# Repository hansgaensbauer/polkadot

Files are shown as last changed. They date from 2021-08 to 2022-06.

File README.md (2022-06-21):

# polkadot
A low cost, standalone LoRa mesh network using STM32 and the SX1276.

## Firmware
The firmware implements a limited (and highly simplified) version of the AODV routing algorithm. Identical nodes running identical firmware can route a mesh automatically and efficiently without outside intervention. Additional nodes (which can also be running "factory" firmware) will route themselves when they power on. 

## Hardware





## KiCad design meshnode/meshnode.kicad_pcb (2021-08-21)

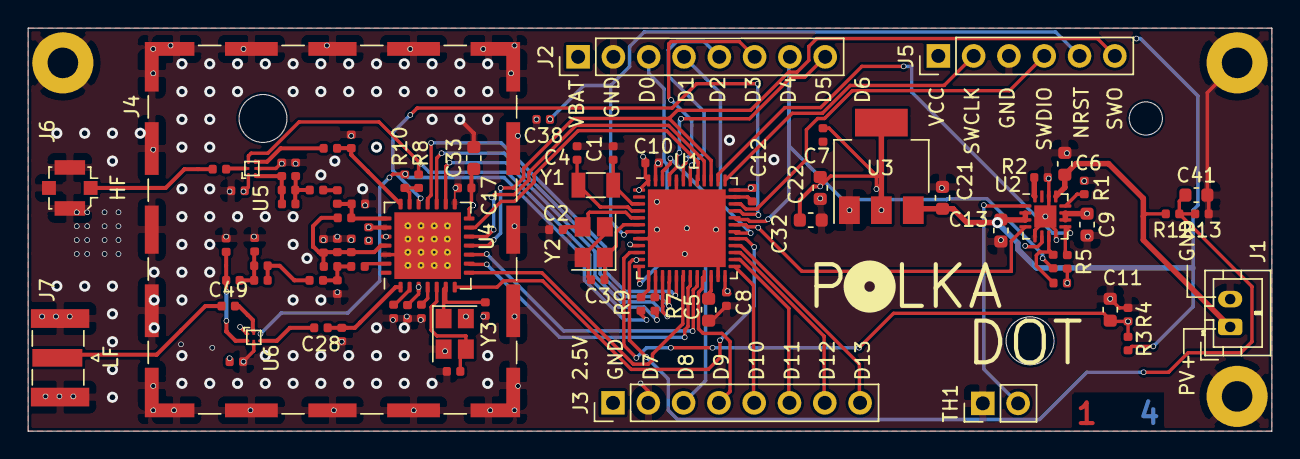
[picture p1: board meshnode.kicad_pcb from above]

Board: 4 copper layers, 89.5 x 29.0 mm, 88 parts (1 on the bottom side), 71 nets.

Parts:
BT1: Battery_Cell; BatteryHolder_Keystone_1042_1x18650
C1, C2, C3, C4, C15, C16, C24, C39: 15p; C_0402_1005Metric
C5, C9, C13: 4.7u; C_0603_1608Metric
C6, C21, C22: 1u; C_0603_1608Metric
C7, C8, C10, C12, C14, C17, C18, C19, C20, C38: 100n; C_0402_1005Metric
C11, C32, C33, C41: 10u; C_0603_1608Metric
C23: 1.5p; C_0402_1005Metric
C25: 10n; C_0402_1005Metric
C26: 33p; C_0402_1005Metric
C27: 18p; C_0402_1005Metric
C28, C35: 22p; C_0402_1005Metric
C29, C30, C47, C49: 47p; C_0402_1005Metric
C31: 3.3p; C_0402_1005Metric
C34: 4.7p; C_0402_1005Metric
C36: 2.7p; C_0402_1005Metric
C37: 1.2p; C_0402_1005Metric
C40: 1.8p; C_0402_1005Metric
C44: 6.8p; C_0402_1005Metric
C45, C46: 1n; C_0402_1005Metric
H1, H2, H3: MountingHole_Pad; MountingHole_2.2mm_M2_Pad
J1: Conn_01x02_Male; JST_PH_B2B-PH-K_1x02_P2.00mm_Vertical
J2, J3: Conn_01x08_Male; PinHeader_1x08_P2.54mm_Vertical
J4: RF_Shield_Two_Pieces; Laird_Technologies_BMI-S-203-F_26.21x26.21mm
J5: SWD; PinHeader_1x06_P2.54mm_Vertical
J6: Conn_Coaxial; U.FL_Molex_MCRF_73412-0110_Vertical
J7: Conn_Coaxial; SMA_Samtec_SMA-J-P-X-ST-EM1_EdgeMount
L1: 2.2n; L_0402_1005Metric
L2, L3: 33n; L_0402_1005Metric
L4: 18n; L_0402_1005Metric
L8: 10n; L_0402_1005Metric
L9: 12n; L_0402_1005Metric
L10: 6.2n; L_0402_1005Metric
L11: 15n; L_0402_1005Metric
R1: 1.18k; R_0402_1005Metric
R2: 1.13k; R_0402_1005Metric
R3, R4, R12: 1Meg; R_0402_1005Metric
R5, R6, R11: 1k; R_0402_1005Metric
R7, R8, R9, R10: 220; R_0402_1005Metric
R13: 100k; R_0402_1005Metric
TH1: 10k; PinHeader_1x02_P2.54mm_Vertical
U1: STM32F401CCUx; QFN-48-1EP_7x7mm_P0.5mm_EP5.6x5.6mm
U2: BQ24074RGT; VQFN-16-1EP_3x3mm_P0.5mm_EP1.6x1.6mm
U3: AZ1117-2.5; SOT-223-3_TabPin2
U4: SX1276; QFN-28-1EP_6x6mm_P0.65mm_EP4.8x4.8mm_ThermalVias
U5, U6: SKY13453-385LF; SKY13453
Y1: 32.786k; Crystal_SMD_3215-2Pin_3.2x1.5mm
Y2: 16Meg; Crystal_SMD_SeikoEpson_TSX3225-4Pin_3.2x2.5mm
Y3: 32Meg; Crystal_SMD_SeikoEpson_TSX3225-4Pin_3.2x2.5mm

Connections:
+2V5: C7.2, C8.2, C10.2, C12.2, C17.2, C19.2, C20.2, C22.1, C32.1, C33.1, C45.1, C46.1, J3.1, J5.1, R5.1, R6.1, U1.1, U1.9, U1.24, U1.36, U1.48, U3.2, U4.3, U4.14, U4.24, U5.1, U6.1
+4V: C9.1, U2.6, U2.10, U2.11
+BATT: BT1.1, C13.1, C21.1, J2.1, R3.2, U2.2, U2.3, U3.3
/CHG_~CE: U1.31, U2.4
/CS_X: U1.33, U4.19
/DIO0: U1.18, U4.8
/DIO1: U1.19, U4.9
/DIO2: U1.20, U4.10
/DIO4: U1.40, U4.12
/DIO5: U1.41, U4.13
/GPIO_0: J2.3, U1.12
/GPIO_1: J2.4, U1.30
/GPIO_2: J2.5, U1.42
/GPIO_3: J2.6, U1.43
/GPIO_5: J2.8, U1.45
/GPIO_6: J3.3, U1.46
/GPIO_7: J3.4, U1.21
/GPIO_8: J3.5, U1.25
/GPIO_9: J3.6, U1.26
/GPIO_10: J3.7, U1.27
/GPIO_11: J3.8, U1.28
/MISO: U1.16, U4.17
/MOSI: U1.17, U4.18
/NRST: C38.1, J5.5, U1.7
/RST: U1.29, U4.7
/RXTX: R8.1, R10.1, U4.20
/RXTX_HF: R7.1, U1.14
/RXTX_LF: R9.1, U1.13
/SCK: U1.15, U4.16
/SWCLK: J5.2, U1.37
/SWDIO: J5.4, U1.34
/SWO: J5.6, U1.39, U4.11
/~CHG: R5.2, U1.38, U2.9
/~PGOOD: J2.7, R11.2, U1.32
GND: BT1.2, C1.1, C2.1, C3.2, C4.2, C5.2, C6.1, C7.1, C8.1, C9.2, C10.1, C11.2, C12.1, C13.2, C14.2, C15.1, C16.2, C17.1, C18.2, C19.1, C20.1, C21.2, C22.2, C23.2, C24.2, C25.2, C29.2, C30.2, C31.2, C32.2, C33.2, C34.1, C38.2, C39.2, C40.1, C41.2, C44.1, C45.2, C46.2, H1.1, H2.1, H3.1, J1.2, J2.2, J3.2, J4.1, J5.3, J6.2, J7.2, L4.2, R1.2, R2.1, R4.1, R13.1, TH1.1, U1.8, U1.23, U1.35, U1.44, U1.47, U1.49, U2.5, U2.8, U2.14, U2.17, U3.1, U4.15, U4.23, U4.26, U4.29, U5.3, U6.3, Y2.2, Y2.4, Y3.2, Y3.4
unnamed: C1.2, U1.3, Y1.1
unnamed: C2.2, U1.5, Y2.3
unnamed: C3.1, U1.6, Y2.1
unnamed: C4.1, U1.4, Y1.2
unnamed: C5.1, U1.22
unnamed: C11.1, R3.1, R4.2, U1.10
unnamed: C14.1, U4.4
unnamed: C15.2, U4.5, Y3.3
unnamed: C16.1, U4.6, Y3.1
unnamed: C18.1, U4.2
unnamed: C23.1, C26.2, L3.1, U4.22
unnamed: C24.1, C27.1, L1.2, L2.2
unnamed: C25.1, C29.1, C30.1, L2.1, L3.2, U4.25
unnamed: C26.1, L8.1
unnamed: C27.2, C36.1, L9.1
unnamed: C28.1, L4.1, U4.1
unnamed: C28.2, U6.4
unnamed: C31.1, C35.1, U4.21
unnamed: C34.2, C37.1, L8.2, L10.1
unnamed: C35.2, U5.4
unnamed: C36.2, C39.1, L9.2, L11.1
unnamed: C37.2, C40.2, L10.2, U5.2
unnamed: C41.1, R12.1, R13.2, U1.11
unnamed: C44.2, L11.2, U6.2
unnamed: C47.1, J6.1
unnamed: C47.2, U5.6
unnamed: C49.1, J7.1
unnamed: C49.2, U6.6
unnamed: L1.1, U4.27
unnamed: R1.1, U2.12
unnamed: R2.2, U2.16
unnamed: R7.2, R8.2, U5.5
unnamed: R9.2, R10.2, U6.5
unnamed: R6.2, R11.1, U2.7
unnamed: TH1.2, U2.1
VPP: C6.2, J1.1, R12.2, U2.13

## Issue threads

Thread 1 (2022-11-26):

STM32L073

tcpipchip, 2022-11-26:
Hey
Let’s port to this stm32L073 ?
I have here 4 units of a module using this processor and sx1276

tcpipchip, 2022-11-27:
`../Core/Src/main.c: In function 'MX_GPIO_Init':
../Core/Src/main.c:417:28: error: 'DATA_RDY_Pin' undeclared (first use in this function)
  417 |   HAL_GPIO_WritePin(GPIOB, DATA_RDY_Pin|LED_Pin, GPIO_PIN_RESET);
      |                            ^~~~~~~~~~~~
../Core/Src/main.c:417:28: note: each undeclared identifier is reported only once for each function it appears in
../Core/Src/main.c:420:21: error: 'SX1276_CS_GPIO_Port' undeclared (first use in this function)
  420 |   HAL_GPIO_WritePin(SX1276_CS_GPIO_Port, SX1276_CS_Pin, GPIO_PIN_RESET);
      |                     ^~~~~~~~~~~~~~~~~~~
../Core/Src/main.c:420:42: error: 'SX1276_CS_Pin' undeclared (first use in this function); did you mean 'SX1276_Init'?
  420 |   HAL_GPIO_WritePin(SX1276_CS_GPIO_Port, SX1276_CS_Pin, GPIO_PIN_RESET);
      |                                          ^~~~~~~~~~~~~
      |                                          SX1276_Init
../Core/Src/main.c:429:25: error: 'XDONE_Pin' undeclared (first use in this function)
  429 |   GPIO_InitStruct.Pin = XDONE_Pin;
      |                         ^~~~~~~~~
../Core/Src/main.c:432:17: error: 'XDONE_GPIO_Port' undeclared (first use in this function); did you mean 'LED_GPIO_Port'?
  432 |   HAL_GPIO_Init(XDONE_GPIO_Port, &GPIO_InitStruct);
      |                 ^~~~~~~~~~~~~~~
      |                 LED_GPIO_Port
../Core/Src/sx1276.c: In function 'SX1276_Write_Register':
../Core/Src/sx1276.c:12:20: error: 'SX1276_CS_GPIO_Port' undeclared (first use in this function)
   12 |  HAL_GPIO_WritePin(SX1276_CS_GPIO_Port, SX1276_CS_Pin, GPIO_PIN_RESET);  //activate CS
      |                    ^~~~~~~~~~~~~~~~~~~
../Core/Src/sx1276.c:12:20: note: each undeclared identifier is reported only once for each function it appears in
../Core/Src/main.c:442:25: error: 'SPI2_AS_Pin' undeclared (first use in this function)
  442 |   GPIO_InitStruct.Pin = SPI2_AS_Pin;
      |                         ^~~~~~~~~~~
../Core/Src/sx1276.c:12:41: error: 'SX1276_CS_Pin' undeclared (first use in this function); did you mean 'SX1276_Init'?
   12 |  HAL_GPIO_WritePin(SX1276_CS_GPIO_Port, SX1276_CS_Pin, GPIO_PIN_RESET);  //activate CS
      |                                         ^~~~~~~~~~~~~
      |                                         SX1276_Init
../Core/Src/main.c:445:17: error: 'SPI2_AS_GPIO_Port' undeclared (first use in this function)
  445 |   HAL_GPIO_Init(SPI2_AS_GPIO_Port, &GPIO_InitStruct);
      |                 ^~~~~~~~~~~~~~~~~
../Core/Src/main.c: In function 'HAL_GPIO_EXTI_Callback':
../Core/Src/main.c:463:17: error: 'XDONE_Pin' undeclared (first use in this function)
  463 |  if(GPIO_Pin == XDONE_Pin && rx_flag){
      |                 ^~~~~~~~~
../Core/Src/sx1276.c: In function 'SX1276_Write_Burst':
../Core/Src/sx1276.c:26:20: error: 'SX1276_CS_GPIO_Port' undeclared (first use in this function)
   26 |  HAL_GPIO_WritePin(SX1276_CS_GPIO_Port, SX1276_CS_Pin, GPIO_PIN_RESET);  //activate CS
      |                    ^~~~~~~~~~~~~~~~~~~
../Core/Src/sx1276.c:26:41: error: 'SX1276_CS_Pin' undeclared (first use in this function); did you mean 'SX1276_Init'?
   26 |  HAL_GPIO_WritePin(SX1276_CS_GPIO_Port, SX1276_CS_Pin, GPIO_PIN_RESET);  //activate CS
      |                                         ^~~~~~~~~~~~~
      |                                         SX1276_Init
../Core/Src/main.c: In function 'spi_transfer':
../Core/Src/main.c:471:20: error: 'DATA_RDY_GPIO_Port' undeclared (first use in this function)
  471 |  HAL_GPIO_WritePin(DATA_RDY_GPIO_Port, DATA_RDY_Pin, GPIO_PIN_SET);
      |                    ^~~~~~~~~~~~~~~~~~
../Core/Src/main.c:471:40: error: 'DATA_RDY_Pin' undeclared (first use in this function)
  471 |  HAL_GPIO_WritePin(DATA_RDY_GPIO_Port, DATA_RDY_Pin, GPIO_PIN_SET);
      |                                        ^~~~~~~~~~~~
../Core/Src/sx1276.c: In function 'SX1276_Read_Register':
../Core/Src/sx1276.c:38:20: error: 'SX1276_CS_GPIO_Port' undeclared (first use in this function)
   38 |  HAL_GPIO_WritePin(SX1276_CS_GPIO_Port, SX1276_CS_Pin, GPIO_PIN_RESET);  //activate CS
      |                    ^~~~~~~~~~~~~~~~~~~
../Core/Src/sx1276.c:38:41: error: 'SX1276_CS_Pin' undeclared (first use in this function); did you mean 'SX1276_Init'?
   38 |  HAL_GPIO_WritePin(SX1276_CS_GPIO_Port, SX1276_CS_Pin, GPIO_PIN_RESET);  //activate CS
      |                                         ^~~~~~~~~~~~~
      |                                         SX1276_Init
../Core/Src/main.c:472:29: error: 'SPI2_AS_GPIO_Port' undeclared (first use in this function)
  472 |     while (HAL_GPIO_ReadPin(SPI2_AS_GPIO_Port, SPI2_AS_Pin));  //wait for AS pin
      |                             ^~~~~~~~~~~~~~~~~
../Core/Src/main.c:472:48: error: 'SPI2_AS_Pin' undeclared (first use in this function)
  472 |     while (HAL_GPIO_ReadPin(SPI2_AS_GPIO_Port, SPI2_AS_Pin));  //wait for AS pin
      |                                                ^~~~~~~~~~~
../Core/Src/sx1276.c: In function 'SX1276_Read_Burst':
../Core/Src/sx1276.c:48:20: error: 'SX1276_CS_GPIO_Port' undeclared (first use in this function)
   48 |  HAL_GPIO_WritePin(SX1276_CS_GPIO_Port, SX1276_CS_Pin, GPIO_PIN_RESET);  //activate CS;
      |                    ^~~~~~~~~~~~~~~~~~~
make: *** [Core/Src/subdir.mk:40: Core/Src/main.o] Error 1
make: *** Waiting for unfinished jobs....
../Core/Src/sx1276.c:48:41: error: 'SX1276_CS_Pin' undeclared (first use in this function); did you mean 'SX1276_Init'?
   48 |  HAL_GPIO_WritePin(SX1276_CS_GPIO_Port, SX1276_CS_Pin, GPIO_PIN_RESET);  //activate CS;
      |                                         ^~~~~~~~~~~~~
      |                                         SX1276_Init
../Core/Src/sx1276.c: In function 'SX1276_Transmit_Blocking':
../Core/Src/sx1276.c:117:26: error: 'XDONE_GPIO_Port' undeclared (first use in this function); did you mean 'LED_GPIO_Port'?
  117 |  while(!HAL_GPIO_ReadPin(XDONE_GPIO_Port, XDONE_Pin)); //wait for the transmit to finish   //TODO - add timeout
      |                          ^~~~~~~~~~~~~~~
      |                          LED_GPIO_Port
../Core/Src/sx1276.c:117:43: error: 'XDONE_Pin' undeclared (first use in this function)
  117 |  while(!HAL_GPIO_ReadPin(XDONE_GPIO_Port, XDONE_Pin)); //wait for the transmit to finish   //TODO - add timeout
      |                                           ^~~~~~~~~
../Core/Src/sx1276.c: In function 'SX1276_Receive_Blocking':
../Core/Src/sx1276.c:150:26: error: 'XDONE_GPIO_Port' undeclared (first use in this function); did you mean 'LED_GPIO_Port'?
  150 |  while(!HAL_GPIO_ReadPin(XDONE_GPIO_Port, XDONE_Pin)){
      |                          ^~~~~~~~~~~~~~~
      |                          LED_GPIO_Port
../Core/Src/sx1276.c:150:43: error: 'XDONE_Pin' undeclared (first use in this function)
  150 |  while(!HAL_GPIO_ReadPin(XDONE_GPIO_Port, XDONE_Pin)){
      |                                           ^~~~~~~~~
make: *** [Core/Src/subdir.mk:40: Core/Src/sx1276.o] Error 1
"make -j4 all" terminated with exit code 2. Build might be incomplete.`

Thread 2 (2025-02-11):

Can it be used as a Meshtastic device?

universish, 2025-02-11:
ETS32 is usually used in meshtastic devices. You managed to create a mesh network with STM32. The Meshtastic team tried to do this, but to no avail.
Is your device using LoRa P2P?
I wonder if your device and software can be used for meshtastic?

______________________________________________________________________________________________
Note: I wrote in the issue section because there is no discussion section. this is not a bug.

hansgaensbauer, 2025-02-12:
I suspect that the hardware is compatible with meshtastic, but the firmware uses a custom implementation of AODV. It looks like the SX1276 is used on several of the meshtastic boards, so I imagine that a port of the meshtastic firmware to the STM32 that uses the SX1276 driver from polkadot would work fine.

universish, 2025-02-13:
thanks

Closed 2025-02-13.

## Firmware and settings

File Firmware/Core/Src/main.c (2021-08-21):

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
/* Includes ------------------------------------------------------------------*/
#include "main.h"

/* USER CODE BEGIN Includes */
#include "sx1276.h"
#include "polkadot.h"
#include <stdlib.h>
/* USER CODE END Includes */

/* USER CODE BEGIN PD */
#define PI_NODE 0		//this  determines whether or not this node is "special" or "stock"
#define DATA_REQ 55
/* USER CODE END PD */

ADC_HandleTypeDef hadc1;

I2C_HandleTypeDef hi2c3;

RTC_HandleTypeDef hrtc;

SPI_HandleTypeDef hspi1;

/* USER CODE BEGIN PV */

uint8_t data[16] = "hello world!\n\r";			//UART Transmit Buffer
uint8_t cmd_rx_buf[16];				//receive buffer for mesh commands from Pi
uint8_t cmd_tx_buf[16];
volatile uint8_t tx_len = 5;

volatile unsigned char xdone_flag = 0;
volatile unsigned char rx_flag = 0;
volatile unsigned char spi_flag = 0;
volatile unsigned char spi_rx_tx = 0;

/* USER CODE END PV */

void SystemClock_Config(void);
static void MX_GPIO_Init(void);
static void MX_RTC_Init(void);
static void MX_SPI1_Init(void);
static void MX_ADC1_Init(void);
static void MX_I2C3_Init(void);
/* USER CODE BEGIN PFP */

//prototypes for functions used directly in main
uint8_t spi_transfer(uint8_t data[], uint8_t len);
uint16_t readTemp();

/* USER CODE END PFP */

/**
  * @brief  The application entry point.
  * @retval int
  */
int main(void)
{
  /* MCU Configuration--------------------------------------------------------*/

  /* Reset of all peripherals, Initializes the Flash interface and the Systick. */
  HAL_Init();

  /* Configure the system clock */
  SystemClock_Config();

  /* Initialize all configured peripherals */
  MX_GPIO_Init();
  MX_RTC_Init();
  MX_SPI1_Init();
  MX_ADC1_Init();
  MX_I2C3_Init();
  /* USER CODE BEGIN 2 */
  SX1276_Init(SYNC_WORD, 24);  //Initialize the SX1276

  //PHASE 3 Demo:
  if(PI_NODE){
	  polkadot_init(4); //the hard-coded address of the Pi Node is 4
  } else {
	  uint32_t unique_seed = get_UID();	//initialize with a random ID
	  DEBUG_PRINT("device id: %d\n\r", unique_seed);
	  srand(unique_seed);
	  uint32_t new_id;
	  new_id = rand();
	  while(new_id < 11){
		  new_id = rand();
	  }
	  DEBUG_PRINT("New ID: %d\n\r", new_id);
	  polkadot_init(new_id);
	  rand_delay();
	  mesh_send_hello();
  }

  //MAIN DEMO2 TEST
//	  polkadot_init(50); //For data-sender
//	  HAL_Delay(100);
//	  mesh_transmit(10, data, 3);

//	  polkadot_init(10);   //For Receiver
//	  polkadot_init(25);  //Intermediate


  //RANGE TEST
//  polkadot_init(1);  //transmitter
//  polkadot_init(10); //receiver



//  //EMI TEST
//  HAL_Delay(100);
//  SX1276_Set_Mode(FSTX);  //set mode to FSTX so PLL is turned on
  SX1276_Start_Receive();
  /* USER CODE END 2 */

  /* Infinite loop */
  /* USER CODE BEGIN WHILE */
  while (1)
  {
    /* USER CODE END WHILE */

    /* USER CODE BEGIN 3 */

//	  //RANGE TEST  -- Transmitter
//	  mesh_transmit(10, data, 16);
//	  SX1276_Start_Receive();
//	  HAL_Delay(1000);

//	  //TRANSMIT TEST
//	  HAL_Delay(2000);
//	  DEBUG_PRINT("Transmitting a Packet\n\r");
//	  HAL_Delay(10);
//	  SX1276_Transmit(data, 20);
//	  DEBUG_PRINT("\n\r");


//	  //RECEIVE TEST
//	  uint8_t length;
//	  SX1276_Receive(nrx_data, &length);
//	  DEBUG_PRINT("Packet Data: ");
//	  DEBUG_PRINT((char *) nrx_data);
//	  DEBUG_PRINT("\n\r\n\r");
//
//	  //RSSI TEST
//	  uint8_t rssivalue = SX1276_Get_RSSI();
//	  DEBUG_PRINT("RSSI Value = %ddB\n\r", rssivalue);

//	  //MESH TEST - Source
//	  //Expected packet - [0, 0, 0, 0, 0, 0, 0, 0, 0, 0, 0, 2, 0, 0, 0, 3, 0, 0, 0, 0, 104, 101, 108, 108, 111, 32, 119, 111, 114, 108, 100, 33, 10, 13, 0, 0]
//	  my_id = 0;
//	  uint8_t cast_result = mesh_send_data(3, 0, data, 2, 0, my_id, 16);
//	  if(cast_result){
//		  DEBUG_PRINT("Cast Successful\n\r");
//	  } else {
//		  DEBUG_PRINT("Cast Failed\n\r");
//	  }
//	  HAL_Delay(10000);

//	  //Temperature sensor test
//	  uint16_t temp = readTemp();
//	  DEBUG_PRINT("Temp: %d\n\r", temp);
//	  HAL_Delay(1000);

	  //process incoming requests from the Pi
//	  if(spi_flag && !spi_rx_tx && PI_NODE){ //!HAL_GPIO_ReadPin(SPI2_AS_GPIO_Port, SPI2_AS_Pin) && PI_NODE){		//wait for AS pin
//		  spi_flag = 0;
//		  DEBUG_PRINT("Received command:");
//		  printarr(cmd_rx_buf, 5);
//		  DEBUG_PRINT("\n\r");
//		  if(cmd_rx_buf[0] == DATA_REQ){
//			  uint32_t node_addr = cmd_rx_buf[1] << 24 | cmd_rx_buf[2] << 16 | cmd_rx_buf[3] << 8 | cmd_rx_buf[4];
//			  uint8_t data_req_arr[1] = {DATA_REQ};
//			  DEBUG_PRINT("Requesting data from node #%d\n\r", node_addr);
//			  mesh_transmit(node_addr, data_req_arr, 1);
//		  }
//		  SX1276_Start_Receive();		//go for a new packet
//	  }
	  if(xdone_flag){
		  xdone_flag = 0;
		  if(rx_flag){
		      uint8_t len = SX1276_Read_Register(REG_RX_NB_BYTES); //get packet length
		      uint8_t rxbuf[len];
		      SX1276_Read_Burst(REG_FIFO, rxbuf, len);
		      SX1276_Set_Mode(STDBY);
		      DEBUG_PRINT("Entering Packet Handler\n\r");
		      receive_packet_handler(rxbuf, len);
		      SX1276_Start_Receive();
		  }
	  }

  }
  /* USER CODE END 3 */
}

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
/* USER CODE BEGIN 4 */

//GPIO callback. Handles interrupts from the SX1276 and the raspberry pi.
void HAL_GPIO_EXTI_Callback(uint16_t GPIO_Pin){
	if(GPIO_Pin == XDONE_Pin){
		xdone_flag = 1;
	}
	if(GPIO_Pin == SPI2_AS_Pin && PI_NODE){
		HAL_SPI_TransmitReceive(&hspi2, cmd_tx_buf, cmd_rx_buf, tx_len, 1000);
		while (HAL_SPI_GetState(&hspi2) != HAL_SPI_STATE_READY){}
		if(!spi_rx_tx && PI_NODE){ //!HAL_GPIO_ReadPin(SPI2_AS_GPIO_Port, SPI2_AS_Pin) && PI_NODE){		//wait for AS pin
			spi_flag = 0;
			DEBUG_PRINT("Received command:");
			printarr(cmd_rx_buf, 5);
			DEBUG_PRINT("\n\r");
			if(cmd_rx_buf[0] == DATA_REQ){
				uint32_t node_addr = cmd_rx_buf[1] << 24 | cmd_rx_buf[2] << 16 | cmd_rx_buf[3] << 8 | cmd_rx_buf[4];
				uint8_t data_req_arr[1] = {DATA_REQ};
				DEBUG_PRINT("Requesting data from node #%d\n\r", node_addr);
				mesh_transmit(node_addr, data_req_arr, 1);
			  }
		  }
		SX1276_Start_Receive();
	}
}

//read the temperature sensor for the STM32
uint16_t readTemp(){
	DEBUG_PRINT("\tReading Temperature\n\r");
	HAL_ADC_Start(&hadc1);
	HAL_ADC_PollForConversion(&hadc1, 1);
	uint16_t value = HAL_ADC_GetValue(&hadc1);
	return value;
}

//handshaking protocol for communicating with the raspberry pi
uint8_t spi_transfer(uint8_t data[], uint8_t length){
	DEBUG_PRINT("transferring data to the Pi over SPI\n\r");
	spi_rx_tx = 1;
	for(int i = 0; i < length; i ++){
		cmd_tx_buf[i] = data[i];
	}
	tx_len = length;
	HAL_GPIO_WritePin(DATA_RDY_GPIO_Port, DATA_RDY_Pin, GPIO_PIN_SET);
    while (!spi_flag){
    }
    HAL_GPIO_WritePin(DATA_RDY_GPIO_Port, DATA_RDY_Pin, GPIO_PIN_RESET);
    HAL_SPI_Transmit(&hspi2, data, length,100);
    HAL_Delay(50);
    spi_rx_tx = 0;
    tx_len = 5;
    return SUCCESS;
}

//FUNCTION FOR DOING STUFF WITH DATA
uint8_t DATA_RX_HANDLER(struct data_packet rx_pkt){
	//Print the received data to the console
	DEBUG_PRINT("Received Data: ");
	DEBUG_PRINT((char *) rx_pkt.packet_data);
	DEBUG_PRINT("\n\r");
	if(PI_NODE){
		uint8_t spi_data[6];
		spi_data[0] = rx_pkt.packet_data[0];
		spi_data[1] = rx_pkt.packet_data[1];
		spi_data[2] = (rx_pkt.source_id & 0xFF);
		spi_data[3] = (rx_pkt.source_id >> 8) & 0xFF;
		spi_data[4] = (rx_pkt.source_id >> 16) & 0xFF;
		spi_data[5] = (rx_pkt.source_id >> 24) & 0xFF;
		spi_transfer(spi_data, 6);
		SX1276_Start_Receive();
	} else {
		if(rx_pkt.packet_data[0] == DATA_REQ){		//reply with my temperature if that was a data request
			uint16_t mytemp = readTemp();
			uint8_t temppack[2] = {(mytemp & 0xFF), (mytemp >> 8)};
			mesh_transmit(4, temppack, 2);
		}
	}
	return SUCCESS;
}

/* USER CODE END 4 */
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


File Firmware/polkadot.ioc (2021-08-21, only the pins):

Mcu.UserName=STM32F401CCUx
PA5.Signal=SPI1_SCK
PA6.Signal=SPI1_MISO
PA7.Signal=SPI1_MOSI
PA8.Signal=I2C3_SCL
PB4.Signal=I2C3_SDA
PB6.Signal=USART1_TX
PB7.Signal=USART1_RX
PB8.GPIO_Label=LED
PB8.Signal=GPIO_Output

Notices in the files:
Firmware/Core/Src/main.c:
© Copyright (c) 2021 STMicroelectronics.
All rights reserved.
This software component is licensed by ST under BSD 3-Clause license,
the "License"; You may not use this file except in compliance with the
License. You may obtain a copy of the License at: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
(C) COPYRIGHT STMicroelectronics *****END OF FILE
